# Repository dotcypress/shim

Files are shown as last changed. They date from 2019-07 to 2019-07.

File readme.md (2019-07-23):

# SHIM

Tiny ARM Cortex-M0+ Development/Prototyping board.

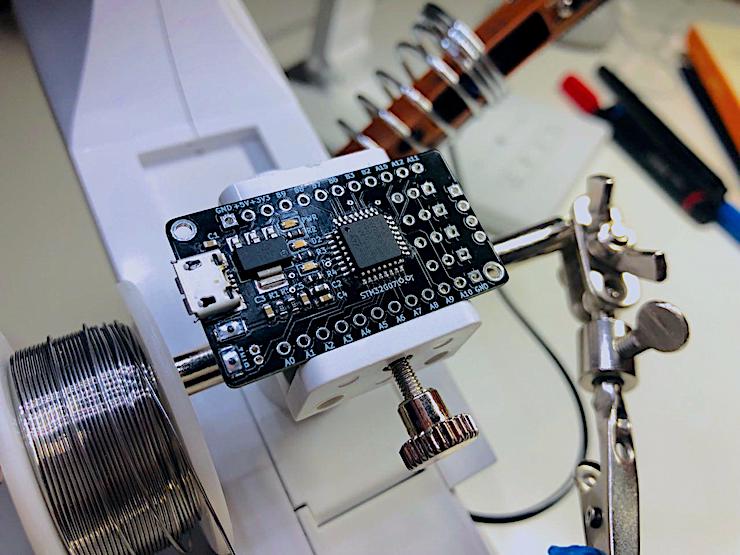
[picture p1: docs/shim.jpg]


## Features

- USB VBUS, ext. VIN, ext. 5V, ext +3.3V 
- Push-buttons: User and Reset 
- LEDs: Power, 2 User LEDs
- Connectors: 2 GPIO, 4 PWM, 1 SWD
- Breadboard friendly

## Resources

- [Schematics](docs/schematics.pdf)
- [Gerber files](docs/fabrication.zip)
- [BOM](docs/bom.csv)
- [KiCad project](kicad/)
- [Rust firmware for 4-DOF robotic arm toy](src/)

## License

Licensed under either of

- Apache License, Version 2.0 ([LICENSE-APACHE](LICENSE-APACHE) or
  http://www.apache.org/licenses/LICENSE-2.0)
- MIT license ([LICENSE-MIT](LICENSE-MIT) or http://opensource.org/licenses/MIT)

at your option.

### Contribution

Unless you explicitly state otherwise, any contribution intentionally submitted
for inclusion in the work by you, as defined in the Apache-2.0 license, shall be
dual licensed as above, without any additional terms or conditions.

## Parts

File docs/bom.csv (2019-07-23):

Part Number | Quantity | Mfr Part Number | Manufacturer Name | Description
STM32G070KBT6 | 1 | STM32G070KBT6 | STMicroelectronics | ARM Microcontrollers - MCU ARM Microcontrollers - MCU Arm Cortex -M0+ 32-bit MCU, 128 KB Flash, 36 KB RAM
649-10103594-0001LF | 1 | 10103594-0001LF | FCI / Amphenol | USB Connectors USB Connectors 5P Quick Connect Micro USB TypeB Rcpt
511-LD1117S33 | 1 | LD1117S33TR | STMicroelectronics | LDO Voltage Regulators LDO Voltage Regulators 3.3V 0.8A Positive
710-150060BS55040 | 1 | 150060BS55040 | Wurth Elektronik | Standard LEDs - SMD Standard LEDs - SMD WL-SMCD SMD Mono SMD 0603 Blue 465nm
710-150060VS55040 | 1 | 150060VS55040 | Wurth Elektronik | Standard LEDs - SMD Standard LEDs - SMD WL-SMCD SMD MonoChip 0603 BrtGrn 575nm
710-150060RS55040 | 1 | 150060RS55040 | Wurth Elektronik | Standard LEDs - SMD Standard LEDs - SMD WL-SMCD SMD MonoChip 0603 Red 632nm
71-CRCW060310K0JNEAC | 2 | CRCW060310K0JNEAC | Vishay | Thick Film Resistors - SMD Thick Film Resistors - SMD 1/10Watt 10Kohms 5% Commercial Use
71-CRCW0603-330-E3 | 3 | CRCW0603330RFKEA | Vishay | Thick Film Resistors - SMD Thick Film Resistors - SMD 1/10watt 330ohms 1%
603-CC0603MPX55BB106 | 1 | CC0603MPX5R5BB106 | Yageo | Multilayer Ceramic Capacitors MLCC - SMD/SMT Multilayer Ceramic Capacitors MLCC - SMD/SMT 10uF 20% 6.3V
603-CC603KRX7R8BB104 | 4 | CC0603KRX7R8BB104 | Yageo | Multilayer Ceramic Capacitors MLCC - SMD/SMT Multilayer Ceramic Capacitors MLCC - SMD/SMT 100nF 25V X7R 10%

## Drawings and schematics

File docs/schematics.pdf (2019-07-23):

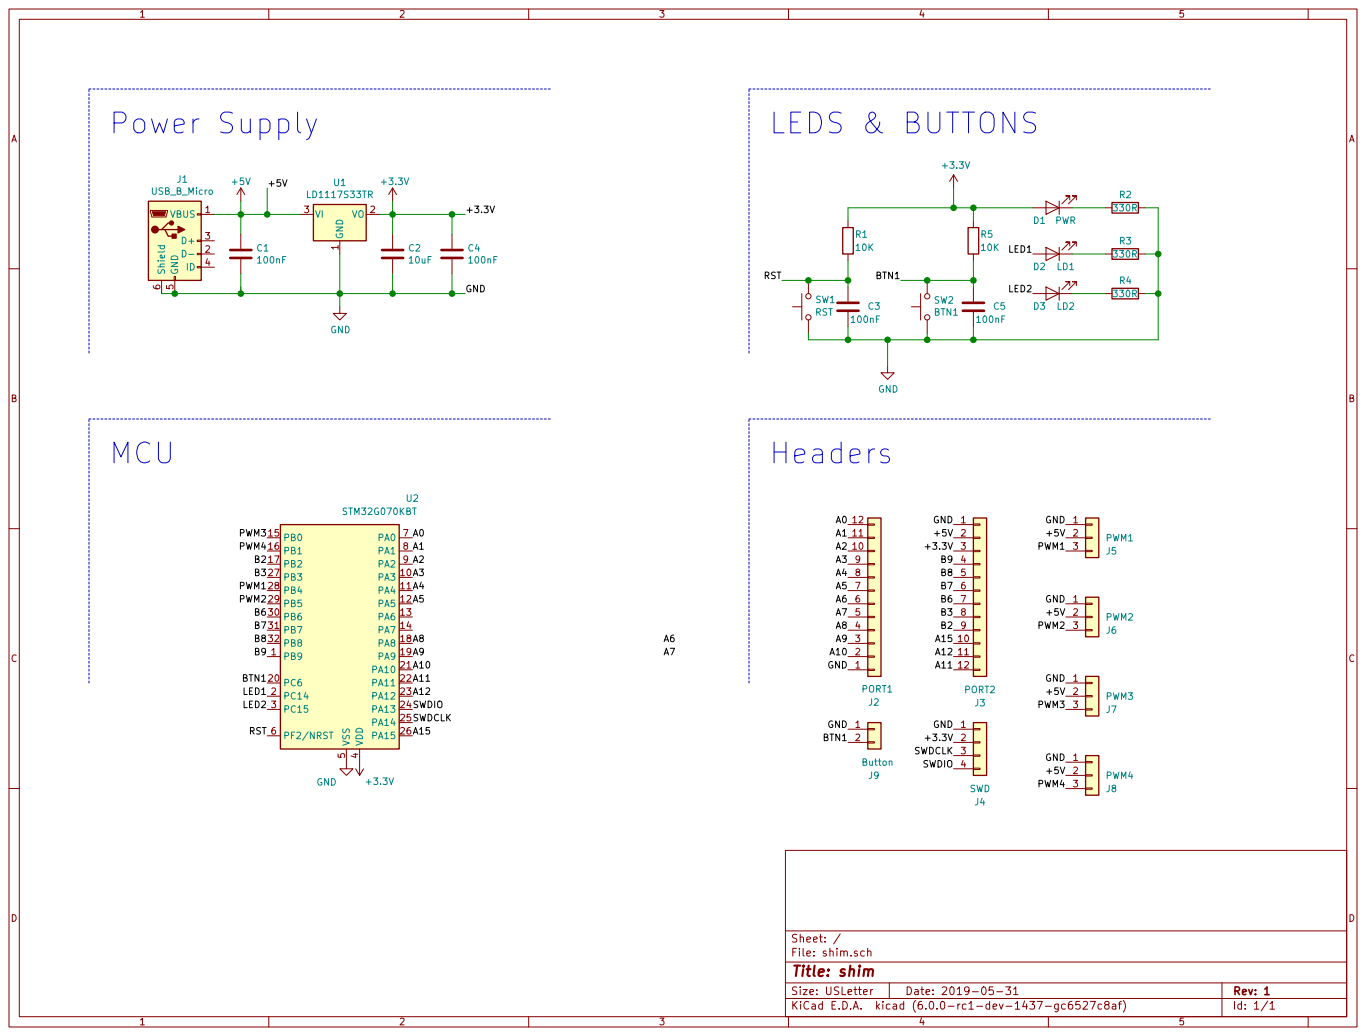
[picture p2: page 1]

File: shim.sch Sheet: / Power Supply

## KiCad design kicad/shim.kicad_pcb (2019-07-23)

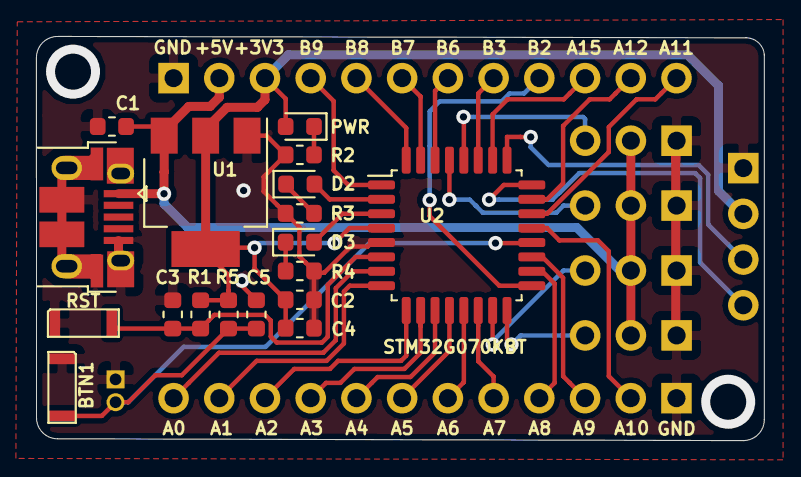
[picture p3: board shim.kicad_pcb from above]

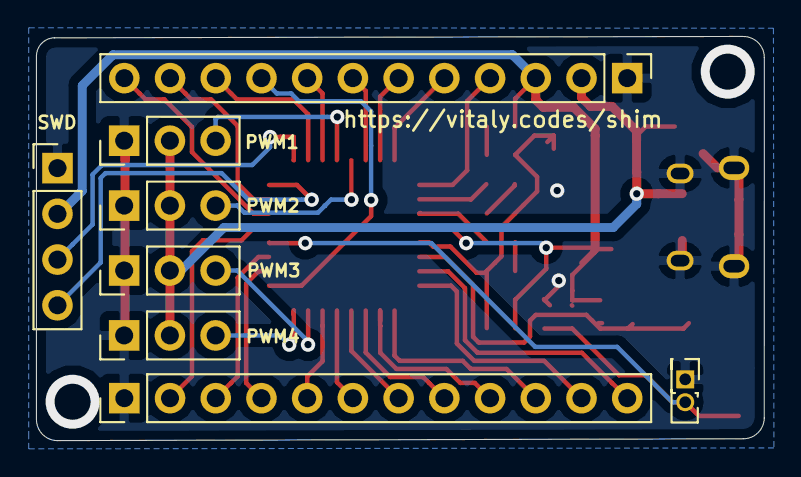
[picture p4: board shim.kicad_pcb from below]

Board: 2 copper layers, 40.4 x 22.5 mm, 26 parts (8 on the bottom side), 34 nets.

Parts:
C1, C3, C4, C5: 100nF; C_0603_1608Metric
C2: 10uF; C_0603_1608Metric
D1: PWR; LED_0603_1608Metric
D2: LD1; LED_0603_1608Metric
D3: LD2; LED_0603_1608Metric
J1: USB_B_Micro; USB_Micro-B_Amphenol_10103594-0001LF_Horizontal
J2: PORT1; PinHeader_1x12_P2.54mm_Vertical
J3: PORT2; PinHeader_1x12_P2.54mm_Vertical
J4: SWD; PinHeader_1x04_P2.54mm_Vertical
J5: PWM1; PinHeader_1x03_P2.54mm_Vertical
J6: PWM2; PinHeader_1x03_P2.54mm_Vertical
J7: PWM3; PinHeader_1x03_P2.54mm_Vertical
J8: PWM4; PinHeader_1x03_P2.54mm_Vertical
J9: Button; PinHeader_2x01_P1.27mm_Vertical
R1, R5: 10K; R_0603_1608Metric
R2, R3, R4: 330R; R_0603_1608Metric
SW1: RST; SW
SW2: BTN1; SW
U1: LD1117S33TR; SOT-223-3_TabPin2
U2: STM32G070KBT; LQFP-32_7x7mm_P0.8mm

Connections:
+3V3: C2.1, C4.1, D1.2, J3.3, J4.2, R1.1, R5.1, U1.2, U2.4
+5V: C1.1, J1.1, J3.2, J5.2, J6.2, J7.2, J8.2, U1.3
/A0: J2.12, U2.7
/A1: J2.11, U2.8
/A2: J2.10, U2.9
/A3: J2.9, U2.10
/A4: J2.8, U2.11
/A5: J2.7, U2.12
/A8: J2.4, U2.18
/A9: J2.3, U2.19
/A10: J2.2, U2.21
/A11: J3.12, U2.22
/A12: J3.11, U2.23
/A15: J3.10, U2.26
/B2: J3.9, U2.17
/B3: J3.8, U2.27
/B6: J3.7, U2.30
/B7: J3.6, U2.31
/B8: J3.5, U2.32
/B9: J3.4, U2.1
/BTN1: C5.2, J9.2, R5.2, SW2.2, U2.20
/LED1: D2.2, U2.2
/LED2: D3.2, U2.3
/PWM1: J5.3, U2.28
/PWM2: J6.3, U2.29
/PWM3: J7.3, U2.15
/PWM4: J8.3, U2.16
/RST: C3.2, R1.2, SW1.2, U2.6
/SWDCLK: J4.3, U2.25
/SWDIO: J4.4, U2.24
GND: C1.2, C2.2, C3.1, C4.2, C5.1, J1.5, J1.6, J2.1, J3.1, J4.1, J5.1, J6.1, J7.1, J8.1, J9.1, R2.1, R3.1, R4.1, SW1.1, SW2.1, U1.1, U2.5
unnamed: D1.1, R2.2
unnamed: D2.1, R3.2
unnamed: D3.1, R4.2

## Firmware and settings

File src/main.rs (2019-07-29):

#![no_std]
#![no_main]
#![deny(warnings)]

extern crate panic_halt;
extern crate stm32g0xx_hal as hal;

mod joystick;
mod robot;
mod servo;

use core::fmt::Write;

use hal::adc::Adc;
use hal::exti::Event;
use hal::gpio::gpioa::*;
use hal::gpio::gpioc::*;
use hal::gpio::{Analog, Output, PushPull, SignalEdge};
use hal::prelude::*;
use hal::pwm::{self, Pwm};
use hal::serial::{Config, Serial};
use hal::stm32;
use hal::timer::Timer;

use joystick::{Joystick, JoystickConfig};
use robot::Robot;

type LogUart = Serial<stm32::USART1>;
type BlueLed = PC14<Output<PushPull>>;
type RedLed = PC15<Output<PushPull>>;
type Pwm1 = Pwm<stm32::TIM3, pwm::C1>;
type Pwm2 = Pwm<stm32::TIM3, pwm::C2>;
type Pwm3 = Pwm<stm32::TIM3, pwm::C3>;
type Pwm4 = Pwm<stm32::TIM3, pwm::C4>;
type JoystickA = Joystick<Adc, PA0<Analog>, PA1<Analog>>;
type JoystickB = Joystick<Adc, PA2<Analog>, PA3<Analog>>;
type RobotArm = Robot<Pwm1, Pwm2, Pwm3, Pwm4>;

#[rtfm::app(device = hal::stm32)]
const APP: () = {
    // Interrupt handlers used to dispatch software tasks
    extern "C" {
        fn PVD();
    }

    // Global resources
    static mut ADC: Adc = ();
    static mut LOG: LogUart = ();
    static mut EXTI: stm32::EXTI = ();
    static mut BLUE_LED: BlueLed = ();
    static mut RED_LED: RedLed = ();
    static mut ROBOT: RobotArm = ();
    static mut JOYSTICK_A: JoystickA = ();
    static mut JOYSTICK_B: JoystickB = ();
    static mut INPUT_TIMER: Timer<stm32::TIM16> = ();
    static mut ANIMATION_TIMER: Timer<stm32::TIM17> = ();

    #[init]
    fn init() {
        let mut rcc = device.RCC.constrain();

        let gpioa = device.GPIOA.split(&mut rcc);
        let gpiob = device.GPIOB.split(&mut rcc);
        let gpioc = device.GPIOC.split(&mut rcc);

        gpioc
            .pc6
            .into_pull_down_input()
            .listen(SignalEdge::Falling, &mut device.EXTI);

        let mut blue_led = gpioc.pc14.into_push_pull_output();
        blue_led.set_low().unwrap();

        let (pwm1, pwm2, pwm3, pwm4) = device.TIM3.pwm(
            (gpiob.pb4, gpiob.pb5, gpiob.pb0, gpiob.pb1),
            210.hz(),
            &mut rcc,
        );

        let mut input_timer = device.TIM16.timer(&mut rcc);
        input_timer.start(100.hz());
        input_timer.listen();

        let mut animation_timer = device.TIM17.timer(&mut rcc);
        animation_timer.start(5.hz());
        animation_timer.listen();

        let usart = device
            .USART1
            .usart(gpioa.pa9, gpioa.pa10, Config::default(), &mut rcc)
            .unwrap();

        let mut adc = device.ADC.constrain(&mut rcc);

        ADC = adc;
        LOG = usart;
        EXTI = device.EXTI;
        ANIMATION_TIMER = animation_timer;
        INPUT_TIMER = input_timer;
        BLUE_LED = blue_led;
        RED_LED = gpioc.pc15.into_push_pull_output();
        ROBOT = Robot::new(pwm1, pwm2, pwm3, pwm4);
        JOYSTICK_A = Joystick::new(
            gpioa.pa0.into_analog(),
            gpioa.pa1.into_analog(),
            JoystickConfig::Invert,
            &mut adc,
        );
        JOYSTICK_B = Joystick::new(
            gpioa.pa2.into_analog(),
            gpioa.pa3.into_analog(),
            JoystickConfig::InvertY,
            &mut adc,
        );
    }

    #[interrupt(binds = TIM16, resources = [INPUT_TIMER, ADC, ROBOT, JOYSTICK_A, JOYSTICK_B])]
    fn process_input() {
        let (grip, elevation) = resources.JOYSTICK_A.read(&mut resources.ADC);
        let (azimuth, stretch) = resources.JOYSTICK_B.read(&mut resources.ADC);

        resources.ROBOT.move_by(grip, azimuth, stretch, elevation);
        resources.INPUT_TIMER.clear_irq();
    }

    #[interrupt(binds = TIM17, resources = [ANIMATION_TIMER, BLUE_LED, RED_LED])]
    fn animate_leds() {
        resources.BLUE_LED.toggle().unwrap();
        resources.RED_LED.toggle().unwrap();

        resources.ANIMATION_TIMER.clear_irq();
    }

    #[interrupt(binds = EXTI4_15, resources = [EXTI], spawn = [print_state])]
    fn on_button_press() {
        resources.EXTI.unpend(Event::GPIO6);
        spawn.print_state().unwrap();
    }

    #[task(resources = [LOG, ROBOT])]
    fn print_state() {
        writeln!(resources.LOG, "{}\r", resources.ROBOT).unwrap();
    }
};

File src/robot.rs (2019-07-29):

use core::f32::consts::PI;
use core::fmt::{Display, Formatter, Result};
use hal::hal::PwmPin;

use crate::servo::Servo;

const HOME_ANGLE: f32 = PI / 2.0;

pub struct Robot<P1, P2, P3, P4> {
    grip: Servo<P1>,
    stretch: Servo<P2>,
    azimuth: Servo<P3>,
    elevation: Servo<P4>,
}

impl<P1, P2, P3, P4> Robot<P1, P2, P3, P4>
where
    P1: PwmPin<Duty = u32>,
    P2: PwmPin<Duty = u32>,
    P3: PwmPin<Duty = u32>,
    P4: PwmPin<Duty = u32>,
{
    pub fn new(grip_ch: P1, stretch_ch: P2, azimuth_ch: P3, elevation_ch: P4) -> Self {
        let mut grip = Servo::new(grip_ch);
        let mut stretch = Servo::new(stretch_ch);
        let mut azimuth = Servo::new(azimuth_ch);
        let mut elevation = Servo::new(elevation_ch);

        grip.set_angle(HOME_ANGLE);
        azimuth.set_angle(HOME_ANGLE);
        stretch.set_angle(HOME_ANGLE);
        elevation.set_angle(HOME_ANGLE);

        Robot {
            grip,
            stretch,
            azimuth,
            elevation,
        }
    }

    pub fn move_by(&mut self, grip: f32, azimuth: f32, stretch: f32, elevation: f32) {
        const DIVIDER: f32 = 128.0;

        let current = self.grip.get_angle();
        self.grip.set_angle(current + grip / DIVIDER);

        let current = self.azimuth.get_angle();
        self.azimuth.set_angle(current + azimuth / DIVIDER);

        let current = self.stretch.get_angle();
        self.stretch.set_angle(current + stretch / DIVIDER);

        let current = self.elevation.get_angle();
        self.elevation.set_angle(current + elevation / DIVIDER);
    }
}

impl<P1, P2, P3, P4> Display for Robot<P1, P2, P3, P4>
where
    P1: PwmPin<Duty = u32>,
    P2: PwmPin<Duty = u32>,
    P3: PwmPin<Duty = u32>,
    P4: PwmPin<Duty = u32>,
{
    fn fmt(&self, f: &mut Formatter<'_>) -> Result {
        write!(
            f,
            "RoboArm\r\n  Gripper:\t{} rad\r\n  Azimuth:\t{} rad\r\n  Stretch:\t{} rad\r\n  Elevation:\t{} rad",
            self.grip.get_angle(),
            self.azimuth.get_angle(),
            self.stretch.get_angle(),
            self.elevation.get_angle()
        )
    }
}

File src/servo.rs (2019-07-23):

use core::f32::consts::PI;
use hal::hal::PwmPin;

pub struct Servo<P> {
    angle: f32,
    zero_duty: f32,
    pwm: P,
}

impl<P> Servo<P>
where
    P: PwmPin<Duty = u32>,
{
    pub fn new(pwm: P) -> Self {
        let mut pwm = pwm;
        let zero_duty = pwm.get_max_duty() as f32 / 10.0;
        pwm.set_duty(0);
        pwm.enable();
        Servo {
            pwm,
            zero_duty,
            angle: 0.0,
        }
    }

    pub fn get_angle(&self) -> f32 {
        self.angle
    }

    pub fn set_angle(&mut self, angle: f32) {
        self.angle = match angle {
            x if (x < 0.0) => 0.0,
            x if (x > PI) => PI,
            x => x,
        };
        let duty = self.zero_duty + self.zero_duty * self.angle * 4.0 / PI;
        self.pwm.set_duty(duty as u32);
    }
}

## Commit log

2019-07-23 update BOM
    [bom.csv]
2019-07-23 add pcb photo
